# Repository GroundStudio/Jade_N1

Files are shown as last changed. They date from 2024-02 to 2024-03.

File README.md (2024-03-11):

GroundStudio Jade N1
====================================
JadeN1

Get it from [ardushop.ro](https://ardushop.ro/ro/118-groundstudio)

Explore all the GroundStudio products at [GroundStudio.ro](https://groundstudio.ro/)

Description
-------------------
Development board based on ATmega328P and HT42B534-2 for USB comunication.

Contents
-------------------

* [/Documentation](https://github.com/GroundStudio/Jade_N1/tree/main/Documentation) -- Pinout.
* [/Hardware](https://github.com/GroundStudio/Jade_N1/tree/main/Hardware) -- Schematics, layout.

Versions
-------------------
*(Not all tags shown)*

* [REV1.0.0]

License
-------------------

This is released under the [Attribution-ShareAlike 4.0 International (CC BY-SA 4.0)](https://creativecommons.org/licenses/by-sa/4.0/) license. 
**You are welcome to use this library for commercial purposes.**

Please consider contributing back to this library or others to help the open-source hardware community continue to thrive and grow! 

Certifications:

[Open Source Hardware Association](https://certification.oshwa.org/ro000025.html)   
   
certification-mark-RO000025-wide (https://certification.oshwa.org/ro000025.html)

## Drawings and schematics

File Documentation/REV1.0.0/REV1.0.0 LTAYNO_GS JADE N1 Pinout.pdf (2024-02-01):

# GroundStudio Jade N1

13

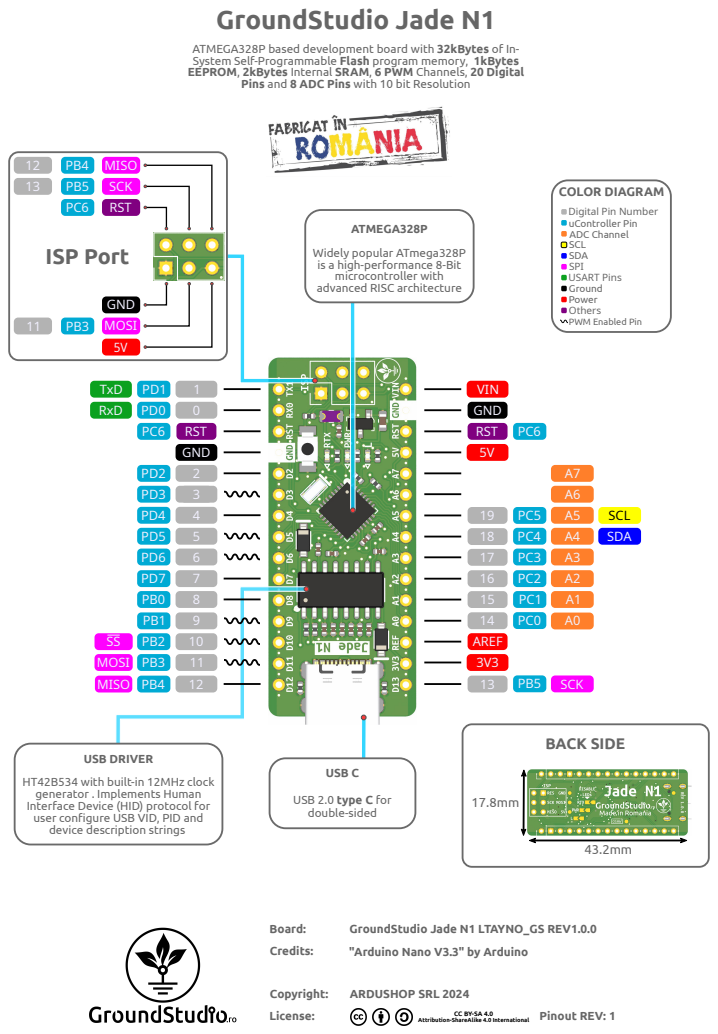
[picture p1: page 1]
SDA; SCL; VIN; GND RST; 17 16 15 14 AREF; PB5 SCK; MISO; MOSI; GND; RST; TxD RxD; BACK SIDE; GND MOSI 5V; SCK; ISP Port; USB DRIVER; USB C; Board:; Credits:; Copyright:; License:; ARDUSHOP SRL 2024; Pinout REV: 1

ATMEGA328P based development board with 32kBytes of In-
System Self-Programmable Flash program memory, 1kBytes
EEPROM, 2kBytes Internal SRAM, 6 PWM Channels, 20 Digital

Pins and 8 ADC Pins with 10 bit Resolution

COLOR DIAGRAM
Digital Pin Number
uController Pin
ADC Channel
SCL
SDA
SPI
USART Pins
Ground
Power
Others
PWM Enabled Pin

ATMEGA328P
Widely popular ATmega328P
is a high-performance 8-Bit
microcontroller with
advanced RISC architecture

HT42B534 with built-in 12MHz clock
generator . Implements Human
Interface Device (HID) protocol for
user configure USB VID, PID and
device description strings

USB 2.0 type C for
double-sided

GroundStudio Jade N1 LTAYNO_GS REV1.0.0
"Arduino Nano V3.3" by Arduino (https://store.arduino.cc/products/arduino-nano)

Attribution-ShareAlike 4.0 International

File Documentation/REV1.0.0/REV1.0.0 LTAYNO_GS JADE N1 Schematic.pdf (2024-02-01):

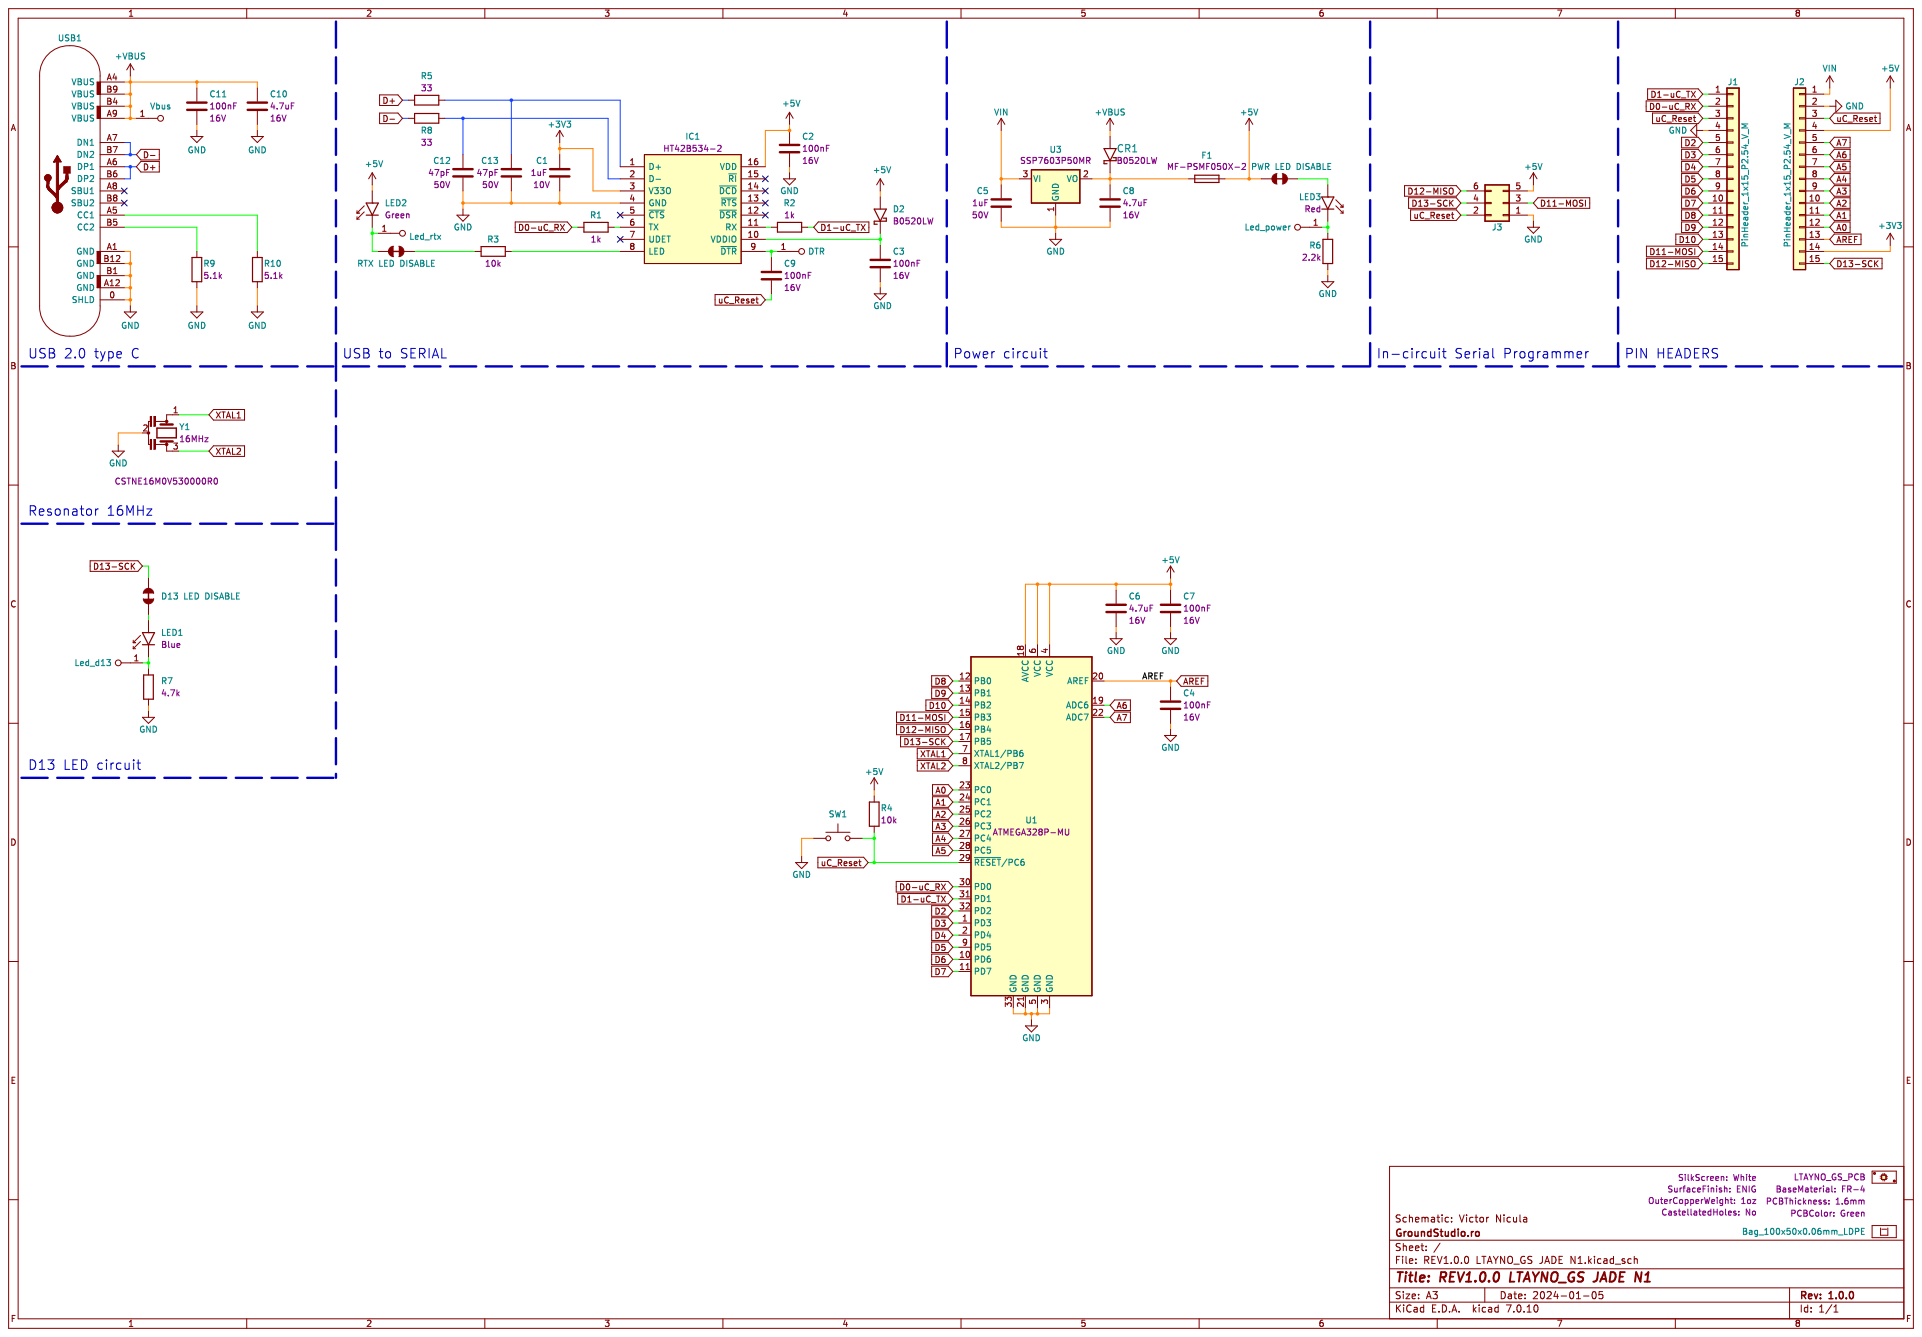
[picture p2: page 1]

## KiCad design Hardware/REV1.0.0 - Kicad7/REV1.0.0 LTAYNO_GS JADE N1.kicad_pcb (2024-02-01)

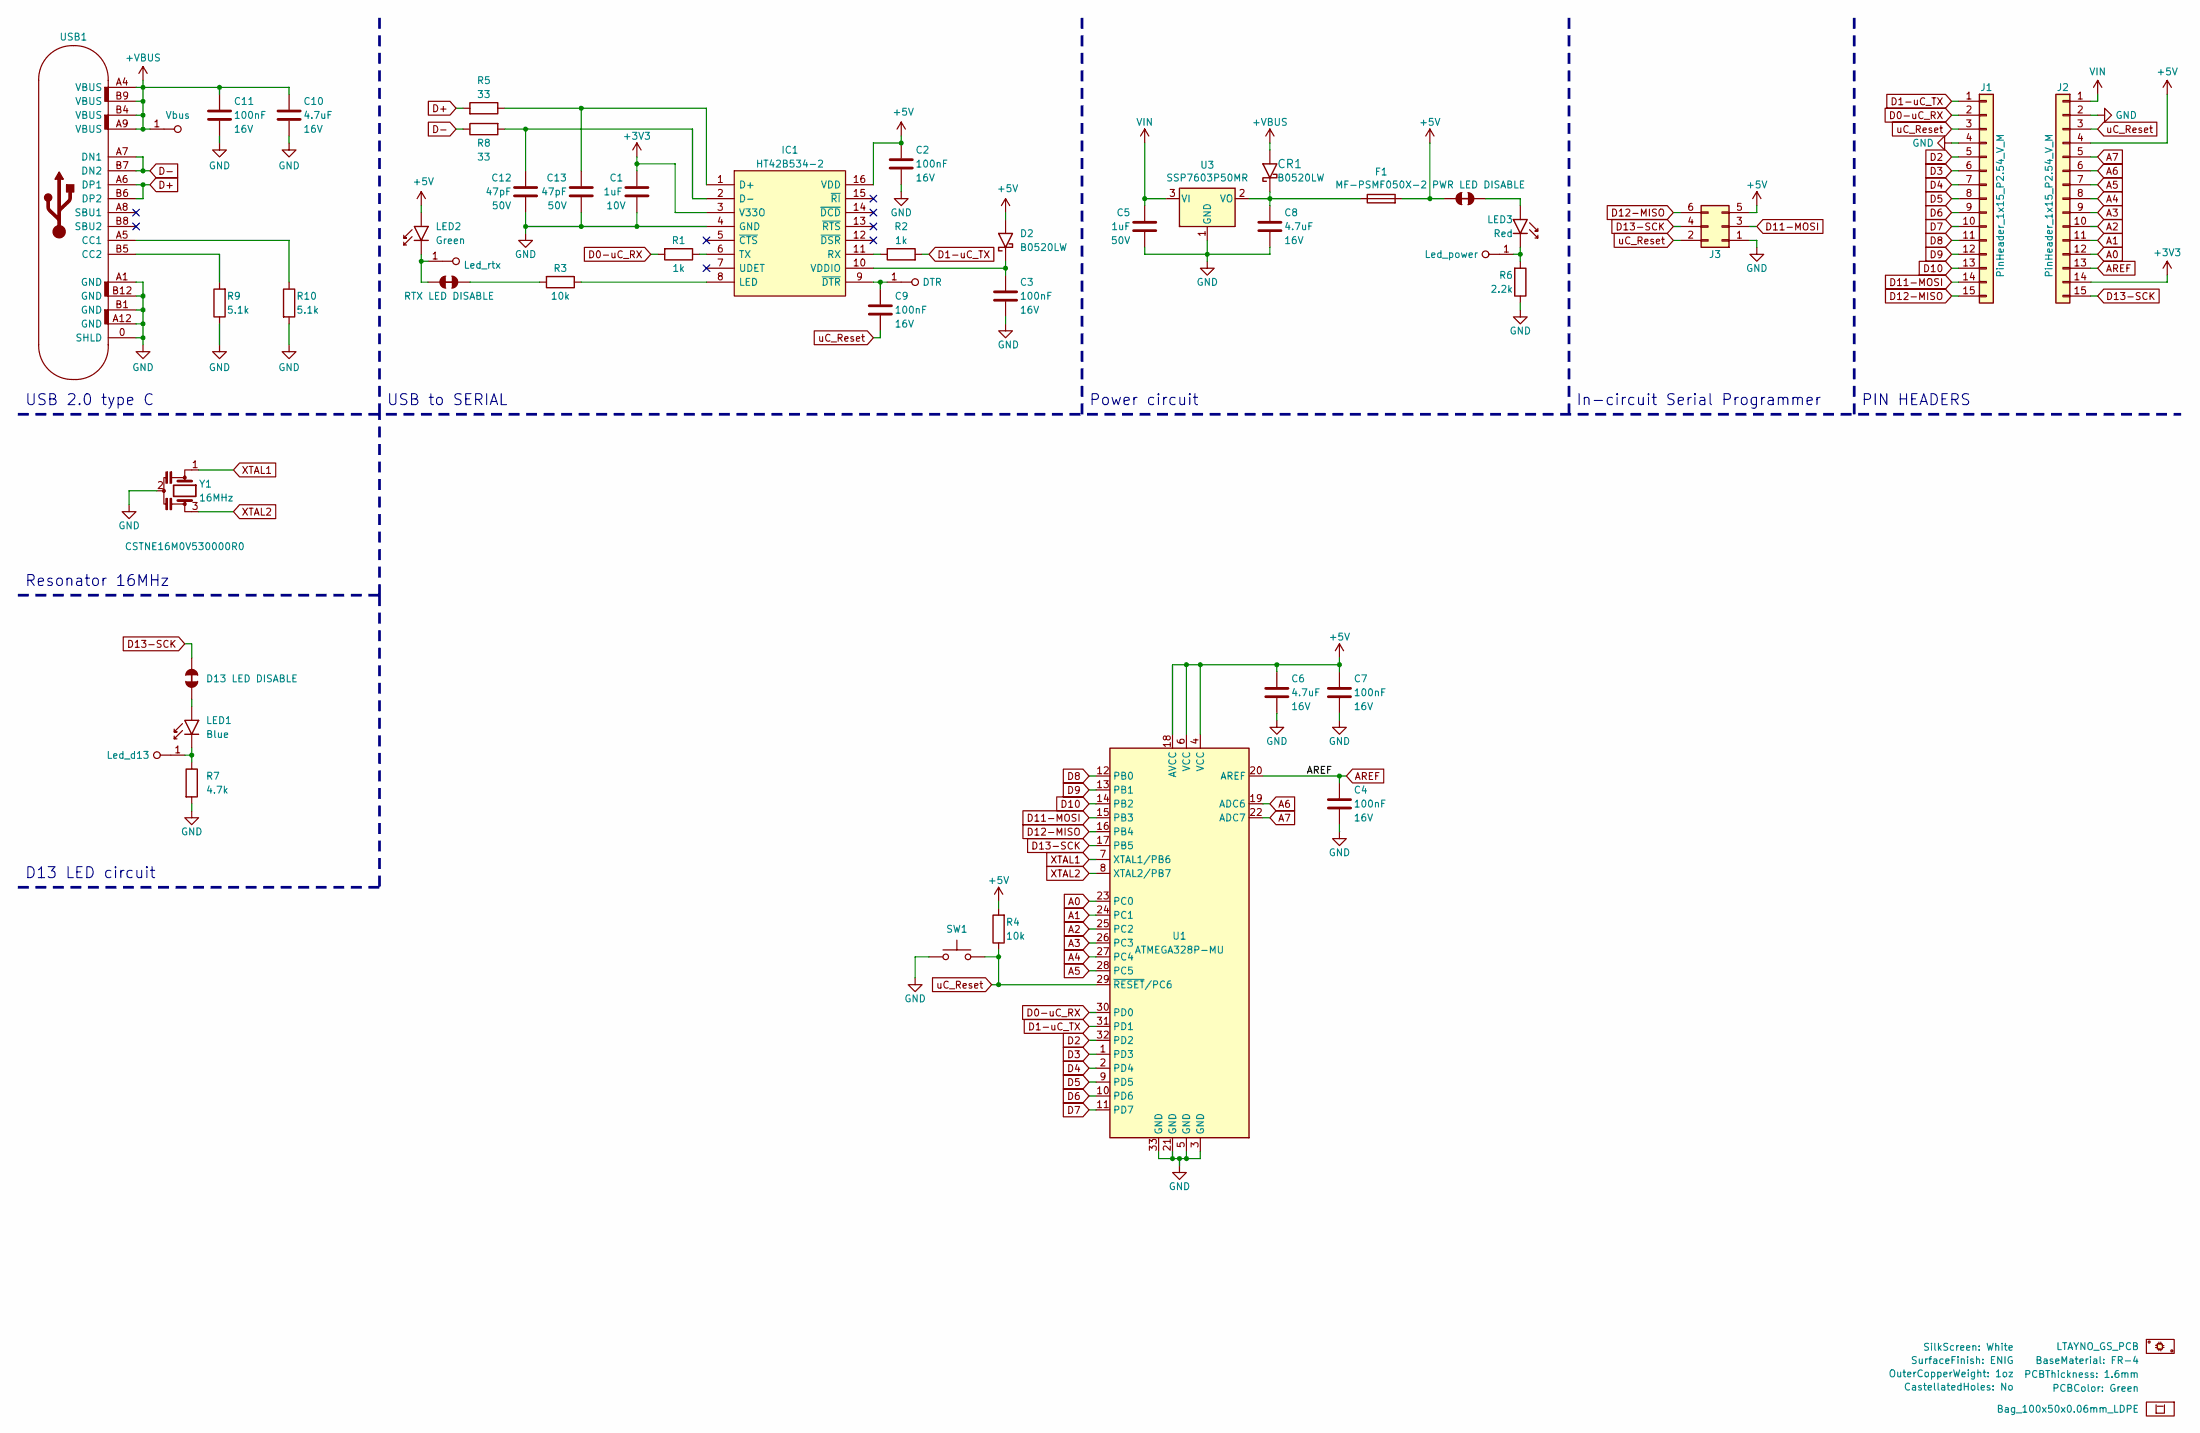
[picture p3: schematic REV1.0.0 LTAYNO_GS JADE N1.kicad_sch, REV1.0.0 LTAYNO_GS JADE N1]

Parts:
B1: Bag_100x50x0.06mm_LDPE; MPN KFHHEG_B
C1: C_0402_1uF_10V; C_0402_alt; Rated voltage 10V; MPN FS15B105K100PKG; LCSC C525324
C2, C4, C7, C9, C11: C_0402_100nF_16V; C_0402_alt; Rated voltage 16V; MPN 0402B104K160CT; LCSC C83056
C3: C_0402_100nF_16V; C_0402_alt; MPN 0402B104K160CT; LCSC C83056
C5: C_0603_1uF_50V; C_0603; Rated voltage 50V; MPN CL10A105KB8NNNC; LCSC C15849
C6, C8, C10: C_0402_4.7uF_16V; C_0402_alt; Rated voltage 16V; MPN C0402X5R475M160NT; LCSC C729453
C12, C13: C_0402_47pF_50V; C_0402_alt; Rated voltage 50V; MPN FN15N470J500PNG; LCSC C525215
CR1: SOD-123 B0520LW; SOD-123; MPN B0520LW; LCSC C89640
D2: SOD-123 B0520LW; SOD-123; MPN B0520LW; LCSC C89640
F1: Fuse_0805_MF-PSMF050X-2; Fuse_0805; MPN MF-PSMF050X-2; LCSC C116170
IC1: SOP-16_150MIL HT42B534-2; SOP-16_150MIL; MPN HT42B534-2; LCSC C493361
J1, J2: PinHeader_1x15_P2.54_V_M; PinHeader_1x15_P2.54mm_Vertical_Male; MPN B-2100S15P-A110; LCSC C124373
J3: PinHeader_2x03_P2.54_V_M; PinHeader_2x03_P2.54mm_Vertical_Male; MPN 210-72-03GB01; LCSC C402781
J4: D13 LED DISABLE; SolderJumper_NC_Default
J5: RTX LED DISABLE; SolderJumper_NC_Default
J6: PWR LED DISABLE; SolderJumper_NC_Default
LED1: LED_0402_BLUE; LED_0402_alt; MPN TZ-P2-0402BTIA1-0.45T; LCSC NA
LED2: LED_0402_GREEN; LED_0402_alt; MPN TZ-P2-0402GTIA1-0.45T; LCSC C688877
LED3: LED_0402_RED; LED_0402_alt; MPN TZ-P2-0402RTIA1-0.45T; LCSC C779449
P1: PCB; MPN LTAYNO_GS_PCB
R1, R2: R_0402_1k; R_0402_alt; MPN RC-02W1001FT; LCSC C226166
R3, R4: R_0402_10k; R_0402_alt; MPN 0402WGJ0103TCE; LCSC C25531
R5, R8: R_0402_33; R_0402_alt; MPN RC-02W33R0FT; LCSC C140161
R6: R_0402_2.2k; R_0402_alt; MPN RC-02W2201FT; LCSC C258093
R7: R_0402_4.7k; R_0402_alt; MPN WR04X4701FTL; LCSC C163826
R9, R10: R_0402_5.1k; R_0402_alt; MPN RC-02W5101FT; LCSC C294638
SW1: TS342A2P-WZ; MPN TS342A2P-WZ; LCSC C557591
TP1: Led_rtx; TestPoint
TP2: Led_power; TestPoint
TP3: Vbus; TestPoint
TP4: Led_d13; TestPoint
TP5: DTR; TestPoint
U1: ATmega328P-MU; QFN-32-1EP_5x5_P0.5_EP3.1x3.1; MPN ATMEGA328P-MU; LCSC C38896
U3: SOT-23-3 SSP7603P50MR; SOT-23-3; MPN SSP7603P50MR; LCSC C411029
USB1: USB_C_FULL; USB_C_C167321; MPN 918-418K2023S40001; LCSC C167321
Y1: RSN_3P_3.2x1.3 CSTNE16M0V; Rsn_muRata_CSTxE-3Pin_3.2x1.3mm; MPN CSTNE16M0V530000R0; LCSC C341521

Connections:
+3V3: C1.1, IC1.3 (V33O), J2.14
+5V: C2.2, C6.1, C7.1, D2.2 (A), F1.2, IC1.16 (VDD), J2.4, J3.5, J6.2, LED2.2 (A), R4.2, U1.4 (VCC), U1.6 (VCC), U1.18 (AVCC)
+VBUS: C10.1, C11.1, CR1.2 (A), TP3.1, USB1.A4 (VBUS), USB1.A9 (VBUS), USB1.B4 (VBUS), USB1.B9 (VBUS)
A0: J2.12, U1.23 (PC0)
A1: J2.11, U1.24 (PC1)
A2: J2.10, U1.25 (PC2)
A3: J2.9, U1.26 (PC3)
A4: J2.8, U1.27 (PC4)
A5: J2.7, U1.28 (PC5)
A6: J2.6, U1.19 (ADC6)
A7: J2.5, U1.22 (ADC7)
AREF: C4.1, J2.13, U1.20 (AREF)
D0-uC_RX: J1.2, R1.2, U1.30 (PD0)
D1-uC_TX: J1.1, R2.2, U1.31 (PD1)
D2: J1.5, U1.32 (PD2)
D3: J1.6, U1.1 (PD3)
D4: J1.7, U1.2 (PD4)
D5: J1.8, U1.9 (PD5)
D6: J1.9, U1.10 (PD6)
D7: J1.10, U1.11 (PD7)
D8: J1.11, U1.12 (PB0)
D9: J1.12, U1.13 (PB1)
D10: J1.13, U1.14 (PB2)
D11-MOSI: J1.14, J3.3, U1.15 (PB3)
D12-MISO: J1.15, J3.6, U1.16 (PB4)
D13-SCK: J2.15, J3.4, J4.1, U1.17 (PB5)
D+: R5.2, USB1.A6 (DP1), USB1.B6 (DP2)
D-: R8.1, USB1.A7 (DN1), USB1.B7 (DN2)
GND: C1.2, C2.1, C3.1, C4.2, C5.2, C6.2, C7.2, C8.2, C10.2, C11.2, C12.1, C13.2, IC1.4 (GND), J1.4, J2.2, J3.1, R6.1, R7.2, R9.1, R10.2, SW1.1, U1.3 (GND), U1.5 (GND), U1.21 (GND), U1.33 (GND), U3.1 (GND), USB1.0 (SHLD), USB1.A1 (GND), USB1.A12 (GND), USB1.B1 (GND), USB1.B12 (GND), Y1.2
unnamed: C8.1, CR1.1 (K), F1.1, U3.2 (VO)
unnamed: C3.2, D2.1 (K), IC1.10 (VDDIO)
unnamed: C13.1, IC1.1 (D+), R5.1
unnamed: C12.2, IC1.2 (D-), R8.2
unnamed: IC1.8 (LED), R3.1
unnamed: IC1.11 (RX), R2.1
unnamed: IC1.6 (TX), R1.1
unnamed: C9.2, IC1.9 (~DTR), TP5.1
unnamed: J5.2, R3.2
unnamed: J4.2, LED1.2 (A)
unnamed: LED1.1 (K), R7.1, TP4.1
unnamed: J5.1, LED2.1 (K), TP1.1
unnamed: J6.1, LED3.2 (A)
unnamed: LED3.1 (K), R6.2, TP2.1
unnamed: R10.1, USB1.A5 (CC1)
unnamed: R9.2, USB1.B5 (CC2)
VIN: C5.1, J2.1, U3.3 (VI)
XTAL1: U1.7 (XTAL1/PB6), Y1.1
XTAL2: U1.8 (XTAL2/PB7), Y1.3
uC_Reset: C9.1, J1.3, J2.3, J3.2, R4.1, SW1.2, U1.29 (~RESET/PC6)

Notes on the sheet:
Resonator 16MHz
PIN HEADERS
USB 2.0 type C
Power circuit
D13 LED circuit
In-circuit Serial Programmer
USB to SERIAL

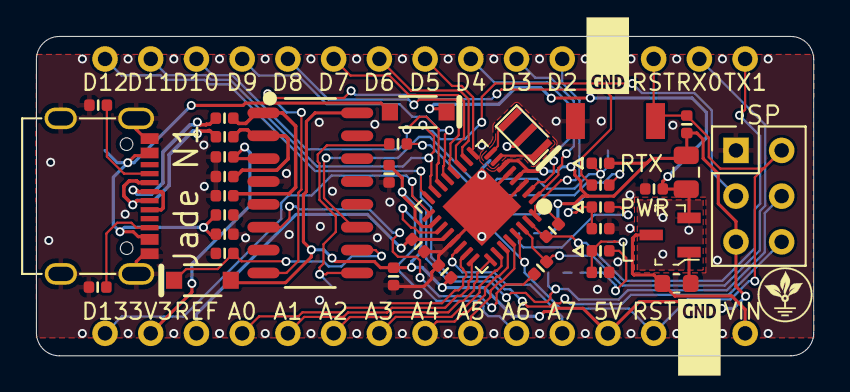
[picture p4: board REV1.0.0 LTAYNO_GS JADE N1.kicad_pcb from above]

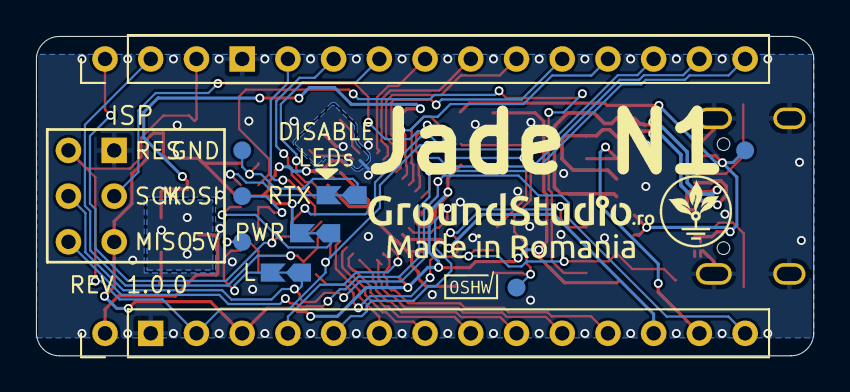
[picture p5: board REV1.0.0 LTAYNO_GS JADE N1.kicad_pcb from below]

Board: 2 copper layers, 43.2 x 17.7 mm, 48 parts (5 on the bottom side), 49 nets.

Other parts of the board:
kibuzzard-6597D01D: G***; kibuzzard-6597D01D
kibuzzard-6597D047: G***; kibuzzard-6597D047
